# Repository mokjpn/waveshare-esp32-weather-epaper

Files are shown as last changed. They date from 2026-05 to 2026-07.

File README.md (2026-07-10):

# Waveshare ESP32 Weather E-Paper

Firmware, relay server, and 3D-printable case files for a battery-powered
weather-map e-paper display.

Sample decoded relay output:

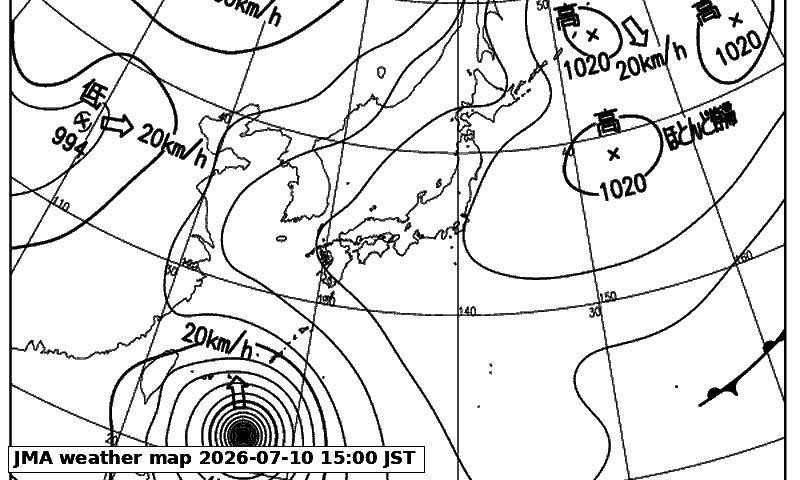
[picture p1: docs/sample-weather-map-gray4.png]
Decoded 4-gray JMA weather map sample


This repository targets:

- Waveshare e-Paper ESP32 Driver Board
- Newer Waveshare 7.5inch e-Paper black/white raw panel, `800x480`,
  4-level grayscale
- Japan Meteorological Agency weather map source data
- A small Python relay server that prepares panel-ready packed bitmap data

## What It Does

1. Wakes on schedule.
2. Connects to Wi-Fi.
3. Synchronizes time with NTP.
4. Fetches a processed weather-map manifest and binary image from the relay.
5. Sends a packed 4-level grayscale weather map to the e-paper panel over SPI.
6. Publishes status events to MQTT.
7. Turns off Wi-Fi/Bluetooth and enters deep sleep.

The default firmware environment is `waveshare_esp32_epd`, which uses the newer
`800x480` panel's 4-gray update path. The relay defaults to `gray4` output:
one packed `800x480`, 2bpp payload of `96000` bytes. The darkest source strokes
are forced to black, with intermediate grays used for lighter map lines and
antialiasing.

## Repository Contents

- `src/main.cpp` - Arduino/PlatformIO firmware entry point
- `lib/WaveshareEsp32Epaper/` - SPI e-paper driver-board support
- `include/app_config.h` - non-secret firmware configuration
- `include/app_secrets.example.h` - template for local secrets
- `relay_server/` - Python JMA weather-map relay
- `cad/waveshare_7in5b_esp32_case.scad` - parametric OpenSCAD case model
- `cad/*.stl` - exported printable parts
- `docs/architecture.md` - firmware and relay API contract
- `docs/case_design.md` - case dimensions, export commands, and print notes

## Secrets

Real Wi-Fi, relay, and MQTT credentials must only be placed in
`include/app_secrets.h`. That file is ignored by Git and is intentionally not
published.

To configure locally:

```sh
cp include/app_secrets.example.h include/app_secrets.h
```

Then edit `include/app_secrets.h` with your local values.

## Build Firmware

Install PlatformIO, then run:

```sh
PLATFORMIO_CORE_DIR=/tmp/pio-core pio run
```

Diagnostic stripe-pattern firmware:

```sh
PLATFORMIO_CORE_DIR=/tmp/pio-core pio run -e waveshare_esp32_epd_diag
```

Upload example:

```sh
PLATFORMIO_CORE_DIR=/tmp/pio-core pio run -e waveshare_esp32_epd -t upload --upload-port /dev/tty.usbmodemXXXX
```

Fallback build targets:

- `waveshare_esp32_epd_1bpp` - newer `800x480` panel with the older 1bpp black/white payload contract
- `waveshare_esp32_epd_7in5bc` - legacy `640x384` Waveshare 7.5inch e-Paper (B), rear label `X02R/171213-180502`

## Run Relay Server

```sh
cd relay_server
python3 -m venv .venv
. .venv/bin/activate
pip install -r requirements.txt
python3 weather_relay.py --bind 0.0.0.0 --port 8080
```

The relay defaults to `800x480` `gray4` output for the newer panel. To serve the
newer panel with the older 1bpp black/white contract instead:

```sh
python3 weather_relay.py --bind 0.0.0.0 --port 8080 --output-format 1bpp
```

For the legacy `640x384` panel path:

```sh
python3 weather_relay.py --bind 0.0.0.0 --port 8080 --image-width 640 --image-height 384
```

## Case Files

The OpenSCAD model exports these printable parts:

```sh
openscad -D 'part="front"' -o cad/waveshare_7in5b_front.stl cad/waveshare_7in5b_esp32_case.scad
openscad -D 'part="back"' -o cad/waveshare_7in5b_back.stl cad/waveshare_7in5b_esp32_case.scad
openscad -D 'part="back_battery"' -o cad/waveshare_7in5b_back_battery.stl cad/waveshare_7in5b_esp32_case.scad
```

The battery-back variant is designed around a cheero Canvas 3200mAh IoT USB-C
Ver. class battery installed landscape and powered through a short internal
USB-A-to-USB-C cable.

## Hardware Notes

- Waveshare ESP32 driver-board pins are fixed:
  `DIN=GPIO14`, `SCLK=GPIO13`, `CS=GPIO15`, `DC=GPIO27`, `RST=GPIO26`,
  `BUSY=GPIO25`.
- Firmware controls driver-board `LED1` through `GPIO2` while awake.
- The default newer-panel path uses Waveshare's `epd7in5_V2` 4-gray update
  sequence.
- The older `7in5bc` path performs a clear refresh before drawing to reduce
  ghosting.
- The raw panel is fragile. Confirm FPC orientation, driver-board DIP switches,
  and case clearances before final assembly.

---

# Waveshare ESP32 Weather E-Paper 日本語

Waveshare ESP32 e-Paper Driver Board を使った、バッテリー駆動の天気図
e-paper 表示機用ファームウェア、リレーサーバー、3Dプリント用ケースファイルです。

リレーサーバーが返す4階調データをデコードしたサンプル:

4階調に変換した気象庁天気図のサンプル

対象ハードウェア:

- Waveshare e-Paper ESP32 Driver Board
- 新しい Waveshare 7.5inch e-Paper 黒白生パネル、`800x480`、4階調対応
- 気象庁の天気図データ
- パネルにそのまま送れるビットマップへ変換する Python リレーサーバー

## 機能

1. スケジュールに従って起床します。
2. Wi-Fi に接続します。
3. NTP で時刻同期します。
4. リレーサーバーから処理済み天気図の manifest とバイナリ画像を取得します。
5. SPI 経由で e-paper パネルへ4階調の天気図を書き込みます。
6. MQTT に状態イベントを送信します。
7. Wi-Fi/Bluetooth を停止して deep sleep に入ります。

通常使用する PlatformIO 環境は `waveshare_esp32_epd` です。新しい
`800x480` パネルの4階調更新経路を使います。リレーサーバーは標準で `gray4`
出力になっており、`800x480`、2bpp、`96000` bytes のペイロードを返します。
濃い線は黒に固定し、薄い地図線やアンチエイリアスは中間グレーとして残します。

## 含まれるもの

- `src/main.cpp` - Arduino/PlatformIO ファームウェア本体
- `lib/WaveshareEsp32Epaper/` - SPI e-paper ドライバーボード対応
- `include/app_config.h` - 秘密情報を含まない設定
- `include/app_secrets.example.h` - ローカル秘密情報用テンプレート
- `relay_server/` - 気象庁天気図リレーサーバー
- `cad/waveshare_7in5b_esp32_case.scad` - OpenSCAD ケースモデル
- `cad/*.stl` - 3Dプリント用STL
- `docs/architecture.md` - ファームウェアとリレーAPIの仕様
- `docs/case_design.md` - ケース寸法、エクスポート方法、印刷メモ

## 秘密情報

実際の Wi-Fi、リレー、MQTT の認証情報は `include/app_secrets.h` のみに置きます。
このファイルは Git の管理対象外で、公開リポジトリには含めません。

ローカル設定は次のように作成します。

```sh
cp include/app_secrets.example.h include/app_secrets.h
```

その後、`include/app_secrets.h` にローカル環境の値を入力してください。

## ファームウェアのビルド

PlatformIO をインストールした上で実行します。

```sh
PLATFORMIO_CORE_DIR=/tmp/pio-core pio run
```

縦縞パターンの診断用ファームウェア:

```sh
PLATFORMIO_CORE_DIR=/tmp/pio-core pio run -e waveshare_esp32_epd_diag
```

アップロード例:

```sh
PLATFORMIO_CORE_DIR=/tmp/pio-core pio run -e waveshare_esp32_epd -t upload --upload-port /dev/tty.usbmodemXXXX
```

退避用のビルドターゲット:

- `waveshare_esp32_epd_1bpp` - 新しい `800x480` パネルを従来の1bpp黒白ペイロードで使う
- `waveshare_esp32_epd_7in5bc` - 旧 `640x384` Waveshare 7.5inch e-Paper (B)、背面ラベル `X02R/171213-180502`

## リレーサーバーの起動

```sh
cd relay_server
python3 -m venv .venv
. .venv/bin/activate
pip install -r requirements.txt
python3 weather_relay.py --bind 0.0.0.0 --port 8080
```

標準では新しいパネル向けに `800x480` `gray4` を返します。新しいパネルを
従来の1bpp黒白ペイロードで使う場合は次のように指定します。

```sh
python3 weather_relay.py --bind 0.0.0.0 --port 8080 --output-format 1bpp
```

旧 `640x384` パネル向けは次のように指定します。

```sh
python3 weather_relay.py --bind 0.0.0.0 --port 8080 --image-width 640 --image-height 384
```

## ケースファイル

OpenSCAD モデルから次の部品を出力できます。

```sh
openscad -D 'part="front"' -o cad/waveshare_7in5b_front.stl cad/waveshare_7in5b_esp32_case.scad
openscad -D 'part="back"' -o cad/waveshare_7in5b_back.stl cad/waveshare_7in5b_esp32_case.scad
openscad -D 'part="back_battery"' -o cad/waveshare_7in5b_back_battery.stl cad/waveshare_7in5b_esp32_case.scad
```

バッテリーバック版は、cheero Canvas 3200mAh IoT USB-C Ver. 相当のバッテリーを
横向きに収め、短い USB-A to USB-C ケーブルでドライバーボードへ給電する前提です。

## ハードウェアメモ

- Waveshare ESP32 ドライバーボードの e-paper ピンは固定です:
  `DIN=GPIO14`, `SCLK=GPIO13`, `CS=GPIO15`, `DC=GPIO27`, `RST=GPIO26`,
  `BUSY=GPIO25`
- ファームウェアは起床中だけ `GPIO2` 経由でドライバーボードの `LED1` を点灯します。
- 標準の新パネル経路では、Waveshare `epd7in5_V2` の4階調更新シーケンスを使います。
- 古い `7in5bc` パネルでは、ゴースト低減のため描画前に白クリアを行います。
- 生パネルは薄く破損しやすいため、FPC の向き、DIPスイッチ、ケースクリアランスを
  最終組み立て前に確認してください。

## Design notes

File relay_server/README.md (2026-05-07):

# Weather Map Relay Server

Small Python relay for the firmware contract in `docs/architecture.md`.

## Endpoints

- `GET /api/weather-map/latest.json`
- `GET /api/weather-map/latest.bin`
- `GET /healthz`

The binary endpoint defaults to exactly `96000` bytes: one `800x480`, packed
2bpp, row-major, 4-level grayscale image for the newer Waveshare 7.5inch
black/white panel. The renderer keeps the darkest strokes black and uses the
intermediate levels for lighter map lines and antialiasing.

## Run

```sh
cd relay_server
python3 -m venv .venv
. .venv/bin/activate
pip install -r requirements.txt
python3 weather_relay.py --bind 0.0.0.0 --port 8080
```

Then point firmware `APP_RELAY_BASE_URL` at the host, for example:

```c
#define APP_RELAY_BASE_URL "http://192.168.1.20:8080"
```

## Configuration

Command-line flags can also be supplied through environment variables.

| Flag | Env var | Default |
| --- | --- | --- |
| `--bind` | `JMA_RELAY_BIND` | `0.0.0.0` |
| `--port` | `JMA_RELAY_PORT` | `8080` |
| `--cache-dir` | `JMA_RELAY_CACHE_DIR` | `relay_server/cache` |
| `--cache-seconds` | `JMA_RELAY_CACHE_SECONDS` | `300` |
| `--threshold` | `JMA_RELAY_THRESHOLD` | `200` |
| `--timeout-seconds` | `JMA_RELAY_TIMEOUT_SECONDS` | `20` |
| `--image-width` | `JMA_RELAY_IMAGE_WIDTH` | `800` |
| `--image-height` | `JMA_RELAY_IMAGE_HEIGHT` | `480` |
| `--output-format` | `JMA_RELAY_OUTPUT_FORMAT` | auto: `gray4`, or `1bpp` for legacy `640x384` |
| `--annotate-timestamp` / `--no-annotate-timestamp` | `JMA_RELAY_ANNOTATE_TIMESTAMP` | `1` |
| `--red-timestamp` / `--no-red-timestamp` | `JMA_RELAY_RED_TIMESTAMP` | auto: `1` for `640x384`, otherwise `0` |
| `--access-log-file` | `JMA_RELAY_ACCESS_LOG_FILE` | stdout only |

For the newer `800x480` panel with the older 1bpp black/white contract, run
with:

```sh
python3 weather_relay.py --bind 0.0.0.0 --port 8080 --output-format 1bpp
```

For the legacy `640x384` Waveshare 7.5inch e-Paper (B) path, run with:

```sh
python3 weather_relay.py --bind 0.0.0.0 --port 8080 --image-width 640 --image-height 384
```

For `gray4`, the relay quantizes the cropped weather map into four levels:
darkest strokes become black, medium strokes become dark/light gray, and the
background stays white. For `1bpp`, lower `--threshold` values keep only darker
source pixels and higher values pick up lighter terrain/coastline strokes. The
relay draws the source time into the rendered image, converting the UTC
timestamp in the JMA image filename to JST, for example
`JMA weather map 2026-05-01 21:00 JST`. On the legacy `640x384` path, the
timestamp is drawn into a second red plane unless `--no-red-timestamp` is
supplied.

The server fetches the JMA monochrome near-Japan current weather map:

- `https://www.jma.go.jp/bosai/weather_map/data/list.json`
- `near_monochrome.now` from that list
- `https://www.jma.go.jp/bosai/weather_map/data/png/<latest near_monochrome.now png>`

If a refresh fails but a valid cached image exists, the server returns the
cached image.

The relay writes access logs with timestamp, method, path, status, response
bytes, duration, remote address, and user-agent. To append logs to a file:

```sh
python3 weather_relay.py \
  --bind 0.0.0.0 \
  --port 8080 \
  --access-log-file /var/log/weather-relay-access.log
```

Example access log line:

```text
2026-05-07T09:00:01+0900 INFO weather_relay.access access method=GET path=/api/weather-map/latest.json status=200 bytes=389 duration_ms=52.1 remote=192.168.1.68 xff=- ua="ESP32HTTPClient"
```

## Monitor

`relay_monitor.py` can run on a Linux server and periodically log which source
weather map the relay is currently serving. It only accesses the relay server;
it does not access JMA directly.

Run one check:

```sh
python3 relay_monitor.py --base-url http://127.0.0.1:8080 --once
```

Run every 30 minutes and append to a log file:

```sh
python3 relay_monitor.py \
  --base-url http://127.0.0.1:8080 \
  --interval-seconds 1800 \
  --log-file /var/log/weather-relay-monitor.log
```

Example log line:

```text
2026-05-05T12:00:00+09:00 OK source_published_at=2026-05-05T00:00:00+00:00 display_label="JMA weather map 2026-05-05 09:00 JST" etag=... size=800x480 bytes=96000 source_area=near_monochrome source_kind=now age_min=180 binary_bytes=96000
```

The monitor also performs a lightweight `HEAD` request to the relay binary
endpoint and logs `binary_bytes`. Use `--no-check-binary` to skip that check.

Environment variables:

| Flag | Env var | Default |
| --- | --- | --- |
| `--base-url` | `JMA_RELAY_MONITOR_BASE_URL` | `http://127.0.0.1:8080` |
| `--interval-seconds` | `JMA_RELAY_MONITOR_INTERVAL_SECONDS` | `1800` |
| `--timeout-seconds` | `JMA_RELAY_MONITOR_TIMEOUT_SECONDS` | `20` |
| `--log-file` | `JMA_RELAY_MONITOR_LOG_FILE` | stdout |
| `--no-check-binary` | `JMA_RELAY_MONITOR_CHECK_BINARY=0` | check enabled |

Example systemd unit:

```ini
[Unit]
Description=Weather relay monitor
After=network-online.target
Wants=network-online.target

[Service]
Type=simple
WorkingDirectory=/opt/waveshare-esp32-weather-epaper/relay_server
ExecStart=/usr/bin/python3 /opt/waveshare-esp32-weather-epaper/relay_server/relay_monitor.py --base-url http://127.0.0.1:8080 --log-file /var/log/weather-relay-monitor.log
Restart=always
RestartSec=10

[Install]
WantedBy=multi-user.target
```

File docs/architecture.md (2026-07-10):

# Waveshare ESP32 E-Paper PoC Architecture

## Scope

This PoC targets these hardware and runtime assumptions.

- Controller and display driver: `Waveshare e-Paper ESP32 Driver Board`
- Default display target: newer `Waveshare 7.5inch e-Paper` black/white raw panel, `800x480`, 4-level grayscale
- Legacy display target: older `Waveshare 7.5inch e-Paper (B)` raw panel, rear label `X02R/171213-180502`, `640x384` driver path
- Framework: `Arduino` on `PlatformIO`
- Power: battery operation with deep sleep
- Network: Wi-Fi to a relay server and MQTT broker

## Firmware Flow

1. Boot on timer wake or button wake.
2. Connect Wi-Fi.
3. Sync time with NTP.
4. Fetch a relay manifest from `APP_RELAY_BASE_URL + /api/weather-map/latest.json`.
5. Download the processed packed image binary.
6. Initialize the SPI e-paper interface.
7. Send the packed 4-level grayscale image.
8. Refresh the display.
9. Publish success or failure to MQTT.
10. Turn off the GPIO2 status LED and Wi-Fi/Bluetooth.
11. Deep sleep until the next scheduled update time.

## Schedule

The schedule is fixed in JST and follows the JMA weather-map observation cadence.
JMA maps are published roughly 2 hours and 10 minutes after the observation time,
so each scheduled run normally fetches the map from the previous 3-hour observation.

- 00:00
- 03:00
- 06:00
- 09:00
- 12:00
- 15:00
- 18:00
- 21:00

Wi-Fi and relay image-fetch failures retry after 10 minutes. Other update failures retry after 5 minutes. MQTT failures are non-fatal.
An image transfer that makes no receive progress for 30 seconds is aborted and treated as a relay image-fetch failure.
Wi-Fi modem sleep is disabled while the device is awake to reduce the chance of stalled image transfers.
The relay's default upstream/render cache TTL is 300 seconds.

## Relay Server Contract

The firmware expects the relay server to provide already processed image data.  
This keeps TLS, scraping, image resizing, center-cropping, and display-format packing off the device.

### Manifest endpoint

- `GET /api/weather-map/latest.json`

Expected JSON:

```json
{
  "image_path": "/api/weather-map/latest.bin",
  "source_url": "https://www.jma.go.jp/bosai/weather_map/",
  "source_image_url": "https://www.jma.go.jp/bosai/weather_map/data/png/...",
  "source_area": "near_monochrome",
  "source_kind": "now",
  "source_published_at": "2026-04-17T12:00:00+00:00",
  "display_label": "JMA weather map 2026-04-17 21:00 JST",
  "etag": "optional-version-string",
  "width": 800,
  "height": 480,
  "bytes": 96000,
  "planes": ["gray4"],
  "format": "gray4",
  "gray_levels": 4,
  "renderer_version": "weather-map-v4-near-monochrome-gray4"
}
```

### Binary endpoint

- `GET /api/weather-map/latest.bin`

Expected payload:

- exactly `96000` bytes by default
- one `800x480`, 2bpp, 4-level grayscale image
- row-major
- four pixels per byte
- each pixel uses the next two high-to-low bits in the byte

## Image Processing Rules

The relay server should transform the JMA image like this.

1. Use the latest published `near_monochrome.now` `日本周辺域 実況天気図`.
2. Scale to width `800` while preserving aspect ratio.
3. Keep the image center fixed.
4. Crop vertically to `480` pixels.
5. Do not add margins.
6. Clear a timestamp label background near the lower-left corner.
7. Draw the source timestamp label in the black plane.
8. Quantize the image to 4 grayscale levels while forcing darkest strokes to black.

## SPI E-Paper Write Strategy

The default firmware target is PlatformIO environment `waveshare_esp32_epd`.
It targets the newer `800x480` black/white 7.5inch panel and uses the 4-level
grayscale refresh path by default.

The fallback 1bpp target is PlatformIO environment `waveshare_esp32_epd_1bpp`.
Use it with relay option `--output-format 1bpp` to keep the newer panel on the
older black/white payload contract.

The legacy firmware target is PlatformIO environment `waveshare_esp32_epd_7in5bc`.
Use it only for the older `640x384` 7.5inch e-Paper (B) path.

The Waveshare ESP32 driver board has fixed e-paper pins:

- `DIN/MOSI`: GPIO14
- `SCLK`: GPIO13
- `CS`: GPIO15
- `DC`: GPIO27
- `RST`: GPIO26
- `BUSY`: GPIO25

Default `waveshare_esp32_epd` write path:

- grayscale source: the `96000` relay bytes
- firmware expands the packed 2bpp image into the `0x10` and `0x13` RAM planes expected by Waveshare's `epd7in5_V2` 4-gray update sequence

Legacy `7in5bc` write path converts the relay's `1bpp` planes into the panel's two-pixels-per-byte transfer format:

- black source: the first `30720` relay bytes
- red source: the second `30720` relay bytes
- red pixels take priority if both planes mark the same pixel

If the relay still serves the older single-plane `30720` byte payload, the firmware treats the missing red plane as white for compatibility.

## Power Notes

The Waveshare ESP32 driver board schematic shows `LED1` connected to `GPIO2`; firmware turns this LED on only while awake and off before deep sleep. A separate USB-UART/power indicator may remain lit independently of firmware. Waveshare documents DIP switch 2 as the USB-UART module power switch for saving power when uploads/serial monitoring are not needed.

## MQTT

The firmware publishes JSON events to:

- `APP_MQTT_TOPIC_BASE/events`

Events include:

- boot
- manifest
- epaper_update
- retry
- sleep

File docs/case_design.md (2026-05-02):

# 7.5inch e-Paper Case Design

## Target hardware
- Waveshare `7.5inch e-Paper (B)` raw panel.
- Waveshare `e-Paper ESP32 Driver Board` Rev.3 with USB Type-C.
- Standard back: no internal battery. Power is supplied externally through USB Type-C.
- Battery back variant: cheero Canvas 3200mAh IoT USB-C Ver. class USB power bank is retained inside the back case; the driver board is powered by a short internal USB cable.

## Source dimensions
- Raw panel outline: `170.2 x 111.2 x 1.18 mm`.
- Active display area: `163.2 x 97.92 mm`.
- ESP32 driver board outline: `48.25 x 29.46 mm`.
- Driver-board adapter outline: `31.75 x 17.50 mm`.
- cheero Canvas 3200mAh IoT USB-C Ver. outline: `50 x 85 x 16 mm`; the battery-back model installs it landscape as `85 x 50 x 16 mm`.

Sources:
- https://www.waveshare.com/7.5inch-e-paper-b.htm
- https://www.waveshare.com/product/e-paper-esp32-driver-board.htm
- https://www.waveshare.com/wiki/E-Paper_ESP32_Driver_Board

## OpenSCAD model
The parametric model is:

```text
cad/waveshare_7in5b_esp32_case.scad
```

It defines a two-piece printed case:
- `back`: rear tray with panel seat, driver-board standoffs, FPC notch, cable slot, and side USB-C opening.
- `back_battery`: deeper rear tray with internal cheero CHE-061C-sized battery pocket and no external USB-C opening.
- Both back variants include two rear keyhole slots for push-pin hanging.
- The battery back includes an internal wire slot from the battery pocket to the ESP32 driver-board area for a short USB-A-to-USB-C power lead.
- The battery back includes a rear access window and finger notch so the battery can be removed without removing the screw-fastened front bezel. The opening is shifted upward so a `3 mm` uncut rear lip remains below the battery to reduce fall-out risk.
- `front`: screw-on front bezel that captures the raw panel outside the active display area.
- `assembly`: translucent preview with panel, driver board, and adapter placeholders.
- `assembly_battery`: translucent preview of the battery-back variant.

Example exports:

```sh
openscad -D 'part="back"' -o back.stl cad/waveshare_7in5b_esp32_case.scad
openscad -D 'part="back_battery"' -o back_battery.stl cad/waveshare_7in5b_esp32_case.scad
openscad -D 'part="front"' -o front.stl cad/waveshare_7in5b_esp32_case.scad
```

## Parameters to verify on real parts
- `display_center_y_offset`: adjust if the front window is not aligned to the active display area.
- `front_lip_depth`, `front_lip_overlap`, `front_panel_top_clearance`, `front_skirt_width`, `front_skirt_panel_gap`, and `front_skirt_case_clearance`: tune the front bezel fit. The downward skirt now sits outside the EPD panel edge and inside the back-case wall; the front face holds the EPD from above with `front_panel_top_clearance`.
- `case_screw_frame_extra`: expands the outer frame so the four case screws sit outside the EPD panel outline. The default `8.0 mm` keeps the M2 screw posts clear of the panel corners.
- `outer_frame_wall`: derived from `wall + case_screw_frame_extra`; USB and panel-FPC cutouts use this effective wall thickness so they still penetrate after the screw frame is widened.
- `board_x_from_right_inner` and `board_y_from_bottom_inner`: move the driver board so the USB-C connector lines up with the case aperture.
- `battery_board_center_x` and `battery_board_y_from_bottom_inner`: move the ESP32 driver board in the battery-back variant. The default aligns the board right edge close to the panel-FPC opening right edge, matching the test-fit photo, with the USB connector side open for cable access.
- `usb_cutout_w`, `usb_cutout_h`, and `board_usb_z_center`: tune for the exact USB-C connector and cable shell.
- `panel_fpc_center_x`, `panel_fpc_notch_w`, and `internal_cable_slot_w`: tune to avoid bending or pinching the raw panel FPC and extension cable.
- `front_skirt_case_clearance`: tune for printer accuracy around the front skirt; start at `0.40 mm`.
- `battery_w`, `battery_h`, `battery_t`, and `battery_clearance`: adjust if using a battery other than cheero CHE-061C. Defaults are landscape installation dimensions.
- `battery_center_x` and `battery_center_y`: tune the battery pocket location. The default keeps the landscape cheero battery above the lower ESP32 board guide while avoiding overlap with the push-pin holes.
- `battery_access_window_center_extra`, `battery_access_window_w`, `battery_access_window_h`, `battery_access_finger_d`, and `battery_rear_retention_lip`: tune the rear battery replacement opening and bottom fall-prevention lip. The default widens only the case-center side of the opening by `2.0 mm` for easier battery removal.
- `guide_rail_clearance`, `guide_rail_wall`, and `guide_rail_h`: tune the loose guide rails used for the battery-back board and battery retention. The battery top/right rails and board right rail are omitted for battery insertion and USB cable access.
- `battery_wire_slot_w`, `battery_wire_slot_h`, `battery_wire_channel_w`, and `battery_wire_channel_h`: reserved for internal cable tuning. The current battery-back layout does not cut a lower cable pass-through; the USB-A lead exits from the open right side of the battery pocket.
- `hook_spacing`, `hook_y`, `hook_head_d`, `hook_slot_w`, and `hook_slot_l`: adjust for the actual push pins/thumbtacks. The default `hook_y = 55.0 mm` keeps the holes clear of the landscape battery window and finger notch.

## Print notes
- Print the `back` with the rear floor on the bed.
- Print `back_battery` with the rear floor on the bed. It is deeper than the standard back because it includes the battery pocket.
- Print the `front` with the outside face on the bed if the bezel face should be clean.
- Use short M2 self-tapping screws for the case corners.
- The raw panel is thin and fragile; add foam tape or thin gasket material only around the non-display border.
- The battery variant intentionally has no outside charging opening. Remove the battery through the rear access window for charging unless a separate charging aperture or external charge connector is added later.
- Do not rely on printed plastic alone to restrain the battery during a fall. Use thin foam tape or a removable strap after confirming thermal clearance.
- The default battery pocket clearance is `3.0 mm` per side to allow real-part variation, cable shells, foam tape, and ordinary FDM printer tolerance.
- The cheero CHE-061C USB-C port is input only; power output is USB-A. Plan the internal power lead as a short USB-A to USB-C cable from the battery to the ESP32 driver board.

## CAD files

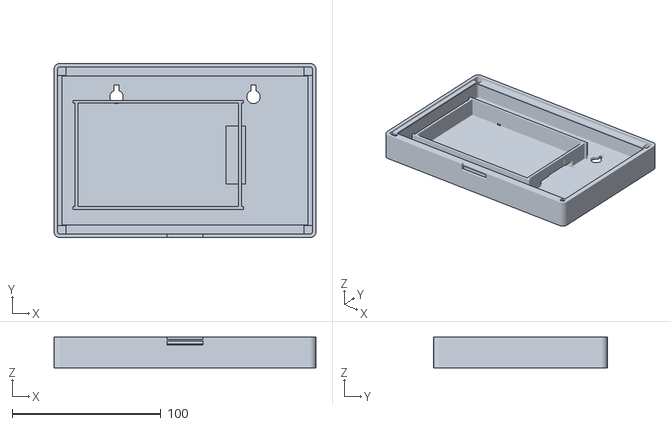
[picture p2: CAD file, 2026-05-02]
cad/waveshare_7in5b_back_battery.stl
176.0 x 117.0 x 20.8

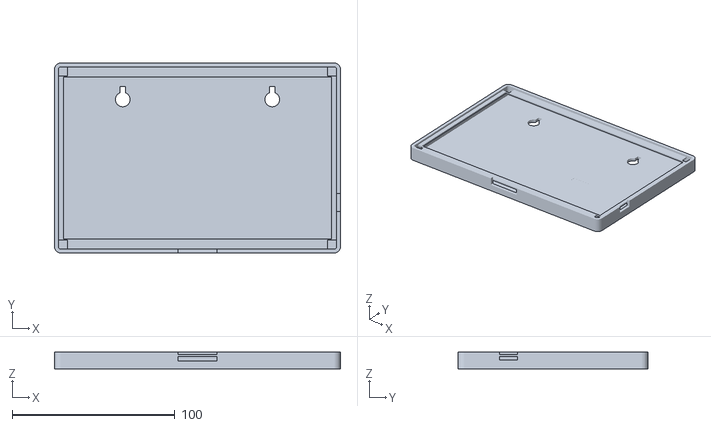
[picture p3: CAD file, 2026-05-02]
cad/waveshare_7in5b_back.stl
176.0 x 117.0 x 10.3

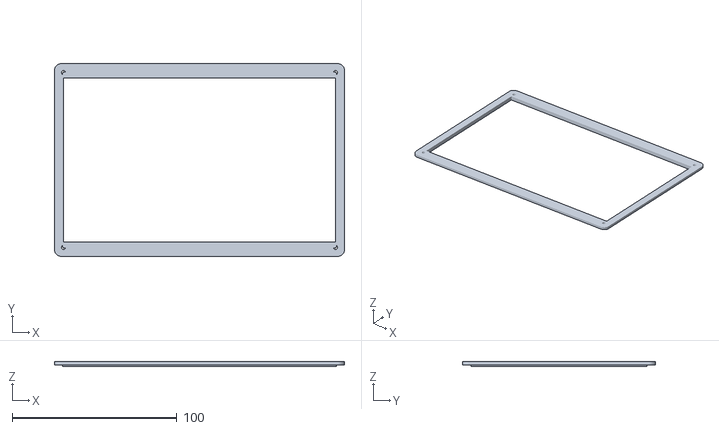
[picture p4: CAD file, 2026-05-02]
cad/waveshare_7in5b_front.stl
176.0 x 117.0 x 3.00

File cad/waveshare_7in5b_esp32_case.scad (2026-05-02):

// Case for Waveshare 7.5inch e-Paper (B) raw panel plus
// Waveshare e-Paper ESP32 Driver Board Rev.3.
//
// Units: millimeters.
//
// Export one printable part at a time:
//   openscad -D 'part="back"'         -o back.stl         cad/waveshare_7in5b_esp32_case.scad
//   openscad -D 'part="back_battery"' -o back_battery.stl cad/waveshare_7in5b_esp32_case.scad
//   openscad -D 'part="front"'        -o front.stl        cad/waveshare_7in5b_esp32_case.scad

$fn = 36;

part = "assembly"; // "assembly", "assembly_battery", "back", "back_battery", "front", "panel", "board"

// Waveshare published dimensions.
panel_w = 170.20;
panel_h = 111.20;
panel_t = 1.18;
display_w = 163.20;
display_h = 97.92;

driver_w = 48.25;
driver_h = 29.46;
driver_t = 1.60;

adapter_w = 31.75;
adapter_h = 17.50;
adapter_t = 1.60;

// cheero Canvas 3200mAh IoT USB-C Ver. (CHE-061C / CHE-061-WH-IOT2)
// published dimensions, installed landscape in the battery-back case.
battery_w = 85.00;
battery_h = 50.00;
battery_t = 16.00;

// Case tuning.
xy_clearance = 0.50;
z_clearance = 0.35;
wall = 2.40;
floor_t = 2.20;
front_t = 2.00;
corner_r = 4.00;
bezel_overlap = 2.10;
front_lip_depth = 1.20;
front_lip_overlap = 0.15;
front_panel_top_clearance = 0.35;
front_skirt_width = 1.20;
front_skirt_panel_gap = 0.60;
front_skirt_case_clearance = 0.40;
case_screw_frame_extra = 8.00;
display_window_clearance = 0.80;
case_screw_d = 2.20;       // M2 self-tapping pilot hole.
case_screw_post_d = 5.20;
case_screw_margin = 5.50;
board_screw_d = 2.20;
board_standoff_d = 5.00;
board_standoff_h = 3.00;
panel_support_w = 8.00;
panel_support_h = 1.20;
battery_clearance = 3.00;
battery_wall = 1.80;
battery_floor_t = 1.80;
battery_retainer_h = 2.00;
battery_wire_slot_w = 20.00;
battery_wire_slot_h = 8.00;
battery_wire_channel_w = 13.00;
battery_wire_channel_h = 5.50;
battery_access_window_center_extra = 2.00;
battery_access_window_w = battery_w + battery_access_window_center_extra;
battery_access_window_h = battery_h;
battery_access_finger_d = 18.00;
battery_rear_retention_lip = 3.00;
guide_rail_clearance = 1.20;
guide_rail_wall = 1.40;
guide_rail_h = 3.00;

// Back hanging holes for push pins/thumbtacks.
hook_spacing = 92.00;
hook_y = 55.00;
hook_head_d = 9.00;
hook_slot_w = 3.20;
hook_slot_l = 8.00;

// Active-area placement inside the raw panel. Waveshare gives the active size;
// measure your panel and adjust these if the display window is not centered.
display_center_x_offset = 0.00;
display_center_y_offset = 0.00;

// Driver-board position on the back, with USB-C opening on the right edge.
board_x_from_right_inner = 1.20;
board_y_from_bottom_inner = 14.00;
battery_board_center_x = -12.00;
battery_board_y_from_bottom_inner = 1.60;
battery_center_x = -38.00;
battery_center_y = 10.00;
board_usb_z_center = floor_t + board_standoff_h + driver_t + 1.50;
usb_cutout_w = 11.00;
usb_cutout_h = 5.60;
usb_cutout_extra_depth = 4.00;

// Cable openings. The raw-panel FPC exits near the lower center.
panel_fpc_center_x = 0.00;
panel_fpc_notch_w = 24.00;
panel_fpc_notch_h = 7.50;
internal_cable_slot_w = 14.00;
internal_cable_slot_h = 4.00;

back_inner_clearance = front_skirt_panel_gap + front_skirt_width + front_skirt_case_clearance;
outer_frame_wall = wall + case_screw_frame_extra;
outer_w = panel_w + 2 * (wall + back_inner_clearance + case_screw_frame_extra);
outer_h = panel_h + 2 * (wall + back_inner_clearance + case_screw_frame_extra);
back_total_h = floor_t + board_standoff_h + driver_t + z_clearance + 3.20;
battery_back_total_h = floor_t + battery_t + battery_clearance + 2.80;
panel_seat_z = back_total_h - panel_t - front_panel_top_clearance;
front_z = back_total_h;

inner_w = panel_w + 2 * back_inner_clearance;
inner_h = panel_h + 2 * back_inner_clearance;

module rounded_box(size, r) {
    hull() {
        for (x = [-size[0] / 2 + r, size[0] / 2 - r])
            for (y = [-size[1] / 2 + r, size[1] / 2 - r])
                translate([x, y, 0])
                    cylinder(h = size[2], r = r);
    }
}

module rect_cut(size, center = true) {
    cube(size, center = center);
}

module screw_post(x, y, h, post_d, hole_d) {
    translate([x, y, 0])
        difference() {
            cylinder(h = h, d = post_d);
            translate([0, 0, -0.1])
                cylinder(h = h + 0.2, d = hole_d);
        }
}

module screw_hole_at(x, y, h, d) {
    translate([x, y, -0.1])
        cylinder(h = h + 0.2, d = d);
}

module keyhole_cut(h) {
    translate([0, 0, -0.1])
        union() {
            cylinder(h = h + 0.2, d = hook_head_d);
            translate([0, hook_slot_l / 2, (h + 0.2) / 2])
                cube([hook_slot_w, hook_slot_l, h + 0.2], center = true);
        }
}

module panel_model() {
    color([0.08, 0.08, 0.08, 0.35])
        translate([0, 0, 0])
            rect_cut([panel_w, panel_h, panel_t]);
    color([0.92, 0.92, 0.88, 0.60])
        translate([display_center_x_offset, display_center_y_offset, panel_t / 2 + 0.02])
            rect_cut([display_w, display_h, 0.08]);
    color([0.95, 0.55, 0.05, 0.55])
        translate([panel_fpc_center_x, -panel_h / 2 - 9.0, panel_t / 2])
            rect_cut([18.0, 18.0, 0.20]);
}

module driver_board_model() {
    color([0.02, 0.18, 0.34, 0.55])
        rect_cut([driver_w, driver_h, driver_t]);
    color([0.80, 0.80, 0.75, 0.70])
        translate([driver_w / 2 - 2.2, 0, driver_t / 2 + 1.2])
            rect_cut([4.5, 9.5, 2.4]);
    color([0.94, 0.94, 0.86, 0.65])
        translate([6.0, driver_h / 2 - 2.6, driver_t / 2 + 1.0])
            rect_cut([28.0, 5.0, 2.0]);
}

module adapter_board_model() {
    color([0.02, 0.33, 0.48, 0.50])
        rect_cut([adapter_w, adapter_h, adapter_t]);
}

module back_case(total_h = back_total_h, usb_cutout_enabled = true, battery_enabled = false, hook_holes_enabled = true) {
    seat_z = total_h - panel_t - front_panel_top_clearance;
    screw_x = outer_w / 2 - case_screw_margin;
    screw_y = outer_h / 2 - case_screw_margin;
    standard_board_cx = outer_w / 2 - wall - board_x_from_right_inner - driver_w / 2;
    standard_board_cy = -outer_h / 2 + wall + board_y_from_bottom_inner + driver_h / 2;
    close_fpc_board_cy = -outer_h / 2 + wall + battery_board_y_from_bottom_inner + driver_h / 2;
    board_cx = battery_enabled ? battery_board_center_x : standard_board_cx;
    board_cy = battery_enabled ? close_fpc_board_cy : standard_board_cy;
    battery_cx = battery_center_x;
    battery_cy = battery_center_y;
    battery_window_cx = battery_cx + battery_access_window_center_extra / 2;
    battery_window_cy = battery_cy + battery_rear_retention_lip;

    difference() {
        union() {
            difference() {
                union() {
                    rounded_box([outer_w, outer_h, total_h], corner_r);

                    for (x = [-screw_x, screw_x])
                        for (y = [-screw_y, screw_y])
                            screw_post(x, y, total_h, case_screw_post_d, case_screw_d);

                    if (!battery_enabled) {
                        translate([board_cx - driver_w / 2 + 4.0, board_cy - driver_h / 2 + 4.0, floor_t])
                            screw_post(0, 0, board_standoff_h, board_standoff_d, board_screw_d);
                        translate([board_cx + driver_w / 2 - 4.0, board_cy - driver_h / 2 + 4.0, floor_t])
                            screw_post(0, 0, board_standoff_h, board_standoff_d, board_screw_d);
                        translate([board_cx - driver_w / 2 + 4.0, board_cy + driver_h / 2 - 4.0, floor_t])
                            screw_post(0, 0, board_standoff_h, board_standoff_d, board_screw_d);
                        translate([board_cx + driver_w / 2 - 4.0, board_cy + driver_h / 2 - 4.0, floor_t])
                            screw_post(0, 0, board_standoff_h, board_standoff_d, board_screw_d);
                    }
                }

                // Main internal cavity.
                translate([0, 0, floor_t])
                    rounded_box([inner_w, inner_h, total_h + 0.4], max(corner_r - wall, 1.0));

                // FPC exit at the raw panel bottom edge.
                translate([panel_fpc_center_x, -outer_h / 2 + outer_frame_wall / 2, seat_z - 0.2])
                    rect_cut([panel_fpc_notch_w, outer_frame_wall + 1.0, panel_fpc_notch_h], center = true);

                // Internal cable pass-through toward the driver board.
                translate([board_cx - driver_w / 2 - 2.0, board_cy + driver_h / 2 + 1.0, floor_t + 2.0])
                    rect_cut([internal_cable_slot_w, internal_cable_slot_h, 4.2]);

                if (usb_cutout_enabled) {
                    // USB-C side aperture. It deliberately has extra size for cable shells.
                    translate([outer_w / 2 - outer_frame_wall / 2, board_cy, board_usb_z_center])
                        rotate([0, 90, 0])
                            rect_cut([usb_cutout_h, usb_cutout_w, outer_frame_wall + usb_cutout_extra_depth], center = true);
                }
            }
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

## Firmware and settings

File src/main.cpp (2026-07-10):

#include <Arduino.h>
#include <WiFi.h>
#include <HTTPClient.h>
#include <PubSubClient.h>
#include <ArduinoJson.h>
#include <algorithm>
#include <vector>
#include <time.h>
#include "app_config.h"
#if __has_include("app_secrets.h")
#include "app_secrets.h"
#else
#include "app_secrets.example.h"
#endif
#include "WaveshareEsp32Epaper.hpp"

namespace {

struct Manifest {
    String imagePath{};
    String sourceUrl{};
    String sourcePublishedAt{};
    String etag{};
    uint16_t width{};
    uint16_t height{};
};

enum class UpdateResult : uint8_t {
    Ok,
    RelayFetchFailed,
    EpaperUpdateFailed,
};

WiFiClient wifiClient;
PubSubClient mqttClient(wifiClient);
WaveshareEsp32Epaper epaper;

struct WifiFailureBacklog {
    uint32_t magic{};
    uint32_t failureCount{};
    int32_t lastStatus{-1};
    time_t lastFailureEpoch{};
    uint32_t lastFailureMillis{};
};

constexpr uint32_t kWifiFailureBacklogMagic = 0x57494642UL;
RTC_DATA_ATTR WifiFailureBacklog gWifiFailureBacklog;

void ensureWifiFailureBacklogInitialized()
{
    if (gWifiFailureBacklog.magic == kWifiFailureBacklogMagic) {
        return;
    }
    gWifiFailureBacklog.magic = kWifiFailureBacklogMagic;
    gWifiFailureBacklog.failureCount = 0;
    gWifiFailureBacklog.lastStatus = -1;
    gWifiFailureBacklog.lastFailureEpoch = 0;
    gWifiFailureBacklog.lastFailureMillis = 0;
}

String formatEventTimeString(time_t epoch, uint32_t millisFallback)
{
    if (epoch > 100000) {
        struct tm utcTm {};
        gmtime_r(&epoch, &utcTm);
        char buffer[32];
        strftime(buffer, sizeof(buffer), "%Y-%m-%dT%H:%M:%SZ", &utcTm);
        return String(buffer);
    }

    const auto fallback = millisFallback > 0 ? millisFallback : millis();
    return String("unsynced-millis-") + String(fallback);
}

String nowEventTimeString()
{
    return formatEventTimeString(time(nullptr), millis());
}

void recordWifiFailure(int32_t wifiStatus)
{
    ensureWifiFailureBacklogInitialized();
    gWifiFailureBacklog.failureCount += 1;
    gWifiFailureBacklog.lastStatus = wifiStatus;
    gWifiFailureBacklog.lastFailureEpoch = time(nullptr);
    gWifiFailureBacklog.lastFailureMillis = millis();
}

void beep(uint16_t freq, uint32_t duration)
{
    (void)freq;
    (void)duration;
}

void setStatusLed(bool on)
{
    if (!app::kStatusLedEnabled || app::kStatusLedPin < 0) {
        return;
    }
    const auto level = on == app::kStatusLedActiveHigh ? HIGH : LOW;
    digitalWrite(app::kStatusLedPin, level);
}

void beginStatusLed()
{
    if (!app::kStatusLedEnabled || app::kStatusLedPin < 0) {
        return;
    }
    pinMode(app::kStatusLedPin, OUTPUT);
    setStatusLed(false);
}

String joinUrl(const char* base, const String& path)
{
    if (path.startsWith("http://") || path.startsWith("https://")) {
        return path;
    }
    String url(base);
    if (url.endsWith("/") && path.startsWith("/")) {
        url.remove(url.length() - 1);
    } else if (!url.endsWith("/") && !path.startsWith("/")) {
        url += '/';
    }
    url += path;
    return url;
}

void publishEvent(const char* event, const char* status, const String& message, JsonDocument* extra = nullptr)
{
    if (!app::kMqttEnabled) {
        return;
    }
    if (!mqttClient.connected()) {
        return;
    }

    StaticJsonDocument<1024> doc;
    doc["device"]   = app::kDeviceName;
    doc["firmware"] = app::kFirmwareVersion;
    doc["event"]    = event;
    doc["status"]   = status;
    doc["message"]  = message;
    doc["event_time"] = nowEventTimeString();
    doc["heap"]     = ESP.getFreeHeap();
    doc["millis"]   = millis();
    if (extra) {
        JsonObject nested = doc["data"].to<JsonObject>();
        for (JsonPairConst kv : extra->as<JsonObjectConst>()) {
            nested[kv.key()] = kv.value();
        }
    }

    char payload[1024];
    const auto len = serializeJson(doc, payload, sizeof(payload));
    mqttClient.publish(APP_MQTT_TOPIC_BASE "/events", reinterpret_cast<const uint8_t*>(payload), len);
}

void publishWifiFailureBacklogIfAny()
{
    ensureWifiFailureBacklogInitialized();
    if (!app::kMqttEnabled || !mqttClient.connected()) {
        return;
    }
    if (gWifiFailureBacklog.failureCount == 0) {
        return;
    }

    StaticJsonDocument<384> extra;
    extra["count"] = gWifiFailureBacklog.failureCount;
    extra["last_status"] = gWifiFailureBacklog.lastStatus;
    extra["last_failed_at"] =
        formatEventTimeString(gWifiFailureBacklog.lastFailureEpoch, gWifiFailureBacklog.lastFailureMillis);
    extra["persisted"] = "rtc";
    publishEvent("wifi_failure_backlog", "warn", "deferred wifi failures observed", &extra);

    gWifiFailureBacklog.failureCount = 0;
    gWifiFailureBacklog.lastStatus = -1;
    gWifiFailureBacklog.lastFailureEpoch = 0;
    gWifiFailureBacklog.lastFailureMillis = 0;
}

bool connectWifi()
{
    WiFi.persistent(false);
    for (uint8_t attempt = 1; attempt <= app::kWifiConnectRetryCount; ++attempt) {
        WiFi.disconnect(true);
        WiFi.mode(WIFI_OFF);
        delay(app::kWifiRadioResetDelayMs);

        WiFi.mode(WIFI_STA);
        WiFi.setSleep(false);
        delay(app::kWifiRadioResetDelayMs);
        WiFi.begin(APP_WIFI_SSID, APP_WIFI_PASSWORD);
        Serial.printf("[wifi] connect attempt=%u/%u\n", attempt, app::kWifiConnectRetryCount);

        const auto start = millis();
        while (WiFi.status() != WL_CONNECTED && millis() - start < app::kWifiConnectTimeoutMs) {
            delay(250);
        }
        if (WiFi.status() == WL_CONNECTED) {
            Serial.printf("[wifi] connected ip=%s rssi=%d sleep=off\n", WiFi.localIP().toString().c_str(),
                          WiFi.RSSI());
            return true;
        }

        Serial.printf("[wifi] attempt=%u failed status=%d\n", attempt, static_cast<int>(WiFi.status()));
        if (attempt < app::kWifiConnectRetryCount) {
            delay(app::kWifiRetryIntervalMs);
        }
    }

    recordWifiFailure(static_cast<int32_t>(WiFi.status()));
    Serial.println("[wifi] connect failed after retries");
    return false;
}

bool connectMqtt()
{
    if (!app::kMqttEnabled) {
        return true;
    }

    mqttClient.setServer(APP_MQTT_HOST, APP_MQTT_PORT);
    mqttClient.setSocketTimeout(app::kMqttSocketTimeoutSeconds);

    String clientId = String(app::kDeviceName) + "-" + String((uint32_t)ESP.getEfuseMac(), HEX);
    bool ok{};
    if (strlen(APP_MQTT_USERNAME) > 0) {
        ok = mqttClient.connect(clientId.c_str(), APP_MQTT_USERNAME, APP_MQTT_PASSWORD);
    } else {
        ok = mqttClient.connect(clientId.c_str());
    }
    if (!ok) {
        Serial.printf("[mqtt] connect failed rc=%d\n", mqttClient.state());
        return false;
    }
    publishEvent("boot", "ok", "mqtt connected");
    return true;
}

bool syncTime()
{
    configTzTime(app::kTimezone, "ntp.nict.jp", "pool.ntp.org", "time.google.com");
    struct tm timeinfo {};
    for (int i = 0; i < 40; ++i) {
        if (getLocalTime(&timeinfo, 250)) {
            Serial.printf("[time] synced %04d-%02d-%02d %02d:%02d:%02d\n", timeinfo.tm_year + 1900,
                          timeinfo.tm_mon + 1, timeinfo.tm_mday, timeinfo.tm_hour, timeinfo.tm_min, timeinfo.tm_sec);
            return true;
        }
    }
    Serial.println("[time] sync failed");
    return false;
}

bool fetchManifest(Manifest& manifest)
{
    const auto url = joinUrl(APP_RELAY_BASE_URL, app::kManifestPath);
    Serial.printf("[http] manifest url=%s\n", url.c_str());

    HTTPClient http;
    int code = 0;
    for (uint8_t attempt = 1; attempt <= app::kHttpRetryCount; ++attempt) {
        http.setTimeout(app::kHttpTimeoutMs);
        http.setReuse(false);
        http.useHTTP10(true);
        if (!http.begin(url)) {
            Serial.println("[http] manifest begin failed");
            return false;
        }
        code = http.GET();
        if (code == HTTP_CODE_OK) {
            break;
        }
        Serial.printf("[http] manifest attempt=%u code=%d error=%s\n", attempt, code,
                      HTTPClient::errorToString(code).c_str());
        http.end();
        delay(app::kHttpRetryDelayMs);
    }
    if (code != HTTP_CODE_OK) {
        return false;
    }

    StaticJsonDocument<1024> doc;
    const auto error = deserializeJson(doc, http.getStream());
    http.end();
    if (error) {
        Serial.printf("[http] manifest parse failed: %s\n", error.c_str());
        return false;
    }

    manifest.imagePath         = doc["image_path"] | "";
    manifest.sourceUrl         = doc["source_url"] | "";
    manifest.sourcePublishedAt = doc["source_published_at"] | "";
    manifest.etag              = doc["etag"] | "";
    manifest.width             = doc["width"] | 0;
    manifest.height            = doc["height"] | 0;

    if (manifest.imagePath.isEmpty()) {
        Serial.println("[http] manifest missing image_path");
        return false;
    }
    if (manifest.width != app::kImageWidth || manifest.height != app::kImageHeight) {
        Serial.printf("[http] unexpected dimensions %u x %u\n", manifest.width, manifest.height);
        return false;
    }
    return true;
}

bool fetchPackedImage(const Manifest& manifest, std::vector<uint8_t>& image)
{
    const auto url = joinUrl(APP_RELAY_BASE_URL, manifest.imagePath);
    Serial.printf("[http] image url=%s\n", url.c_str());

    HTTPClient http;
    int code = 0;
    for (uint8_t attempt = 1; attempt <= app::kHttpRetryCount; ++attempt) {
        http.setTimeout(app::kHttpTimeoutMs);
        http.setReuse(false);
        http.useHTTP10(true);
        if (!http.begin(url)) {
            Serial.println("[http] image begin failed");
            return false;
        }
        code = http.GET();
        if (code == HTTP_CODE_OK) {
            break;
        }
        Serial.printf("[http] image attempt=%u code=%d error=%s\n", attempt, code,
                      HTTPClient::errorToString(code).c_str());
        http.end();
        delay(app::kHttpRetryDelayMs);
    }
    if (code != HTTP_CODE_OK) {
        return false;
    }

    const int length = http.getSize();
    const bool knownLength = length > 0;
    bool acceptedLength = false;
    if (knownLength) {
        const auto imageBytes = static_cast<uint32_t>(length);
        if (app::kEpdFourGray) {
            acceptedLength = imageBytes == app::kImagePayloadBytes;
        } else {
            acceptedLength = imageBytes == app::kPackedImageBytes || imageBytes == app::kImagePayloadBytes;
        }
    }
    if (knownLength && !acceptedLength) {
        Serial.printf("[http] image size mismatch %d\n", length);
        http.end();
        return false;
    }

    const size_t expectedSize = knownLength ? static_cast<size_t>(length) : app::kImagePayloadBytes;
    image.assign(expectedSize, 0xFF);
    auto* stream = http.getStreamPtr();
    size_t offset{};
    uint32_t lastProgressAt = millis();
    while (offset < image.size()) {
        const auto available = stream->available();
        if (available) {
            const auto chunk = std::min<size_t>(available, image.size() - offset);
            const auto read  = stream->readBytes(reinterpret_cast<char*>(image.data() + offset), chunk);
            if (read > 0) {
                offset += read;
                lastProgressAt = millis();
                continue;
            }
        }

        if (!http.connected()) {
            break;
        }
        if (millis() - lastProgressAt >= app::kHttpReceiveIdleTimeoutMs) {
            Serial.printf("[http] image receive idle timeout at %u / %u bytes\n",
                          static_cast<unsigned>(offset), static_cast<unsigned>(image.size()));
            break;
        }
        delay(10);
    }
    http.end();
    if (offset != image.size()) {
        Serial.printf("[http] short image read %u / %u\n", static_cast<unsigned>(offset),
                      static_cast<unsigned>(image.size()));
        return false;
    }
    return true;
}

time_t computeNextSchedule(time_t nowEpoch)
{
    struct tm nowTm {};
    localtime_r(&nowEpoch, &nowTm);

    for (auto hour : app::kScheduleHours) {
        struct tm candidate = nowTm;
        candidate.tm_hour   = hour;
        candidate.tm_min    = app::kScheduleMinute;
        candidate.tm_sec    = 0;
        auto epoch          = mktime(&candidate);
        if (epoch > nowEpoch + 30) {
            return epoch;
        }
    }

    struct tm nextDay = nowTm;
    nextDay.tm_mday += 1;
    nextDay.tm_hour = app::kScheduleHours[0];
    nextDay.tm_min  = app::kScheduleMinute;
    nextDay.tm_sec  = 0;
    return mktime(&nextDay);
}

[[noreturn]] void goSleepSeconds(uint32_t seconds)
{
    Serial.printf("[sleep] %u seconds\n", static_cast<unsigned>(seconds));
    setStatusLed(false);
    delay(100);
    mqttClient.disconnect();
    WiFi.disconnect(true);
    WiFi.mode(WIFI_OFF);
    btStop();
    Serial.flush();
    esp_sleep_enable_timer_wakeup(static_cast<uint64_t>(seconds) * 1000000ULL);
    esp_deep_sleep_start();
    while (true) {
        delay(1000);
    }
}

[[noreturn]] void sleepUntilNextSchedule()
{
    const auto now = time(nullptr);
    if (now <= 100000) {
        goSleepSeconds(app::kRetryDelaySeconds);
    }
    const auto next = computeNextSchedule(now);
    const auto diff = (next > now) ? static_cast<uint32_t>(next - now) : app::kRetryDelaySeconds;
    goSleepSeconds(diff);
}

[[noreturn]] void retryLater(const String& reason)
{
    Serial.printf("[retry] %s\n", reason.c_str());
    publishEvent("retry", "error", reason);
    goSleepSeconds(app::kRetryDelaySeconds);
}

[[noreturn]] void retryLater(const String& reason, uint32_t seconds)
{
    Serial.printf("[retry] %s\n", reason.c_str());
    publishEvent("retry", "error", reason);
    goSleepSeconds(seconds);
}

bool beginDevice()
{
    beginStatusLed();
    return true;
}

#if defined(APP_EPD_DIAGNOSTIC)
std::vector<uint8_t> makeDiagnosticImage()
{
    if (app::kEpdFourGray) {
        std::vector<uint8_t> image(app::kGray4ImageBytes, 0xFF);
        constexpr uint16_t bytesPerRow = app::kImageWidth / 4;
        for (uint16_t y = 0; y < app::kImageHeight; ++y) {
            for (uint16_t xByte = 0; xByte < bytesPerRow; ++xByte) {
                const uint16_t x = xByte * 4;
                const uint8_t shade = (x / 80) % 4;
                uint8_t pixel = 0xC0;
                if (shade == 0) {
                    pixel = 0x00;
                } else if (shade == 1) {
                    pixel = 0x40;
                } else if (shade == 2) {
                    pixel = 0x80;
                }
                image[y * bytesPerRow + xByte] =
                    pixel | (pixel >> 2) | (pixel >> 4) | (pixel >> 6);
            }
        }
        return image;
    }

    std::vector<uint8_t> image(app::kPackedImageBytes, 0xFF);
    constexpr uint16_t bytesPerRow = app::kImageWidth / 8;
    for (uint16_t y = 0; y < app::kImageHeight; ++y) {
        for (uint16_t xByte = 0; xByte < bytesPerRow; ++xByte) {
            const uint16_t x = xByte * 8;
            const bool black = ((x / 80) % 2) == 0;
            image[y * bytesPerRow + xByte] = black ? 0x00 : 0xFF;
        }
    }
    return image;
}

[[noreturn]] void runEpdDiagnostic()
{
    Serial.println("[diag] EPD diagnostic pattern: vertical black/white stripes");
    auto image = makeDiagnosticImage();
    auto result = epaper.writeImage(image);
    Serial.printf("[diag] result ok=%d message=%s\n", result.ok ? 1 : 0, result.message.c_str());
    while (true) {
        delay(1000);
    }
}
#endif

UpdateResult performUpdate()
{
    Manifest manifest;
    if (!fetchManifest(manifest)) {
        return UpdateResult::RelayFetchFailed;
    }

    StaticJsonDocument<512> meta;
    meta["source_url"]          = manifest.sourceUrl;
    meta["source_published_at"] = manifest.sourcePublishedAt;
    meta["etag"]                = manifest.etag;
    publishEvent("manifest", "ok", "manifest fetched", &meta);

    std::vector<uint8_t> image;
    if (!fetchPackedImage(manifest, image)) {
        return UpdateResult::RelayFetchFailed;
    }

    auto result = epaper.writeImage(image);
    StaticJsonDocument<512> updateInfo;
    updateInfo["source_url"] = manifest.sourceUrl;
    updateInfo["published"]  = manifest.sourcePublishedAt;
    updateInfo["transport"]  = "SPI";
    updateInfo["panel"]      = app::kPanelName;

    if (!result.ok) {
        publishEvent("epaper_update", "error", result.message, &updateInfo);
        Serial.printf("[epd] update failed: %s\n", result.message.c_str());
        return UpdateResult::EpaperUpdateFailed;
    }

    publishEvent("epaper_update", "ok", result.message, &updateInfo);
    Serial.println("[epd] update complete");
    beep(3000, 120);
    return UpdateResult::Ok;
}

}  // namespace

void setup()
{
    Serial.begin(115200);
    delay(300);
    ensureWifiFailureBacklogInitialized();
    beginDevice();
    setStatusLed(true);

    Serial.printf("\n[%s] boot firmware=%s\n", app::kDeviceName, app::kFirmwareVersion);
    beep(2200, 40);

#if defined(APP_EPD_DIAGNOSTIC)
    runEpdDiagnostic();
#endif

    if (!connectWifi()) {
        retryLater("wifi connect failed", app::kNetworkRetryDelaySeconds);
    }
    connectMqtt();
    publishWifiFailureBacklogIfAny();
    if (!syncTime()) {
        retryLater("time sync failed");
    }

    const auto updateResult = performUpdate();
    if (updateResult == UpdateResult::RelayFetchFailed) {
        retryLater("relay image fetch failed", app::kNetworkRetryDelaySeconds);
    }
    if (updateResult == UpdateResult::EpaperUpdateFailed) {
        retryLater("epaper update failed");
    }

    publishEvent("sleep", "ok", "sleep until next schedule");
    sleepUntilNextSchedule();
}

void loop()
{
    mqttClient.loop();
    delay(10);
}

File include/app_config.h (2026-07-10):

#pragma once

#include <Arduino.h>

namespace app {

constexpr char kDeviceName[]                  = "waveshare-esp32-weather-epaper";
constexpr char kFirmwareVersion[]             = "0.1.0";
constexpr char kTimezone[]                    = "JST-9";
constexpr uint32_t kWifiConnectTimeoutMs      = 20000;
constexpr uint8_t kWifiConnectRetryCount      = 3;
constexpr uint32_t kWifiRetryIntervalMs       = 2000;
constexpr uint32_t kWifiRadioResetDelayMs     = 300;
constexpr uint32_t kHttpTimeoutMs             = 30000;
constexpr uint32_t kHttpReceiveIdleTimeoutMs  = 30000;
constexpr uint8_t kHttpRetryCount             = 3;
constexpr uint32_t kHttpRetryDelayMs          = 1000;
constexpr uint32_t kMqttSocketTimeoutSeconds  = 10;
constexpr bool kStatusLedEnabled              = true;
constexpr int8_t kStatusLedPin                = 2;  // Waveshare driver board LED1
constexpr bool kStatusLedActiveHigh           = true;
constexpr uint32_t kRetryDelaySeconds         = 5 * 60;
constexpr uint32_t kNetworkRetryDelaySeconds  = 10 * 60;
constexpr uint32_t kEpdBusyTimeoutMs          = 120000;
constexpr bool kEpdClearBeforeUpdate =
#if defined(APP_EPD_7IN5BC)
    true;
#else
    false;
#endif
constexpr bool kEpdAggressiveClear =
#if defined(APP_EPD_7IN5BC)
    true;
#else
    false;
#endif
constexpr bool kEpdGray4ClearBeforeUpdate =
#if defined(APP_EPD_7IN5BC) || defined(APP_EPD_1BPP)
    false;
#else
    true;
#endif
constexpr bool kEpdFourGray =
#if defined(APP_EPD_7IN5BC) || defined(APP_EPD_1BPP)
    false;
#else
    true;
#endif
constexpr char kPanelName[] =
#if defined(APP_EPD_7IN5BC)
    "Waveshare 7.5inch e-Paper (B) legacy 640x384";
#elif defined(APP_EPD_1BPP)
    "Waveshare 7.5inch e-Paper V2 black/white 800x480 1bpp";
#else
    "Waveshare 7.5inch e-Paper V2 black/white 800x480 4-gray";
#endif
constexpr uint16_t kImageWidth =
#if defined(APP_EPD_7IN5BC)
    640;
#else
    800;
#endif
constexpr uint16_t kImageHeight =
#if defined(APP_EPD_7IN5BC)
    384;
#else
    480;
#endif
constexpr uint32_t kPackedImageBytes          = (kImageWidth * kImageHeight) / 8;
constexpr uint32_t kGray4ImageBytes           = (kImageWidth * kImageHeight) / 4;
constexpr uint32_t kImagePayloadBytes =
#if defined(APP_EPD_7IN5BC)
    kPackedImageBytes * 2;
#elif defined(APP_EPD_1BPP)
    kPackedImageBytes;
#else
    kGray4ImageBytes;
#endif
constexpr bool kMqttEnabled                   = true;

constexpr int kScheduleHours[] = {0, 3, 6, 9, 12, 15, 18, 21};
constexpr int kScheduleMinute = 0;

constexpr char kManifestPath[] = "/api/weather-map/latest.json";

}  // namespace app

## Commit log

2026-05-02 Initial public release
    [waveshare_7in5b_back.stl, waveshare_7in5b_back_battery.3mf, waveshare_7in5b_back_battery.stl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]
2026-05-02 Remove unused NFC and M5 references
    [waveshare_7in5b_back_battery.3mf]
2026-07-10 Improve relay image transfer resilience
2026-07-10 Add decoded weather map sample to README
